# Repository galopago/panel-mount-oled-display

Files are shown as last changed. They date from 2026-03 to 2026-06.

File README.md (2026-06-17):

# Panel-mount OLED display — PCB sources

Open-source KiCad designs for a two-board stack that drives a bare 0.96" I2C OLED (128×64) with screw terminals. The boards are meant to fit a 48×29 mm panel-mount enclosure; this repository contains the PCB sources and Gerbers only.

**Full project guide** (assembly, enclosure, BOM with buy links, practical notes):  
[Panel-mount 0.96" bare OLED with screw terminals](https://galopago.github.io/english/panel-mount-oled-display-en/)

## Two-board design

| Board | Folder | Role |
|---|---|---|
| Display board | [`display-board/`](display-board/) | Bare OLED flex (handsoldering footprint), XC6206 3.3 V LDO, auto-reset network, I2C coupling, six 0805 indicator LEDs with independent anode/cathode terminals, 1×8 header to the connector board |
| Connector board | [`connector-board/`](connector-board/) | Double-level 2×8 screw terminals (3.5 mm pitch); routes signals to the field wiring |

The stack is joined with 1×8 pin headers and a spacer so the terminals stay reachable from the side.

## Schematic

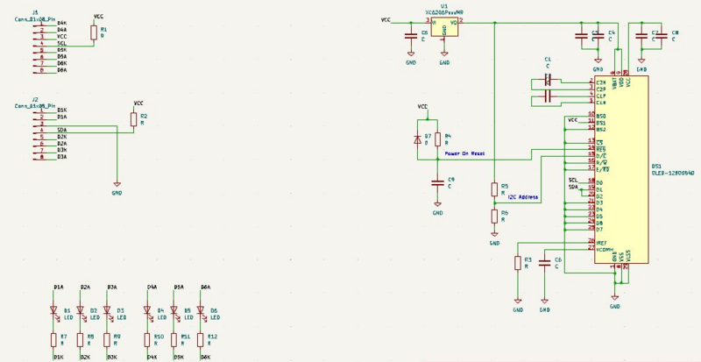
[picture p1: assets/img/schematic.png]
Display and connector board schematic


## Photos

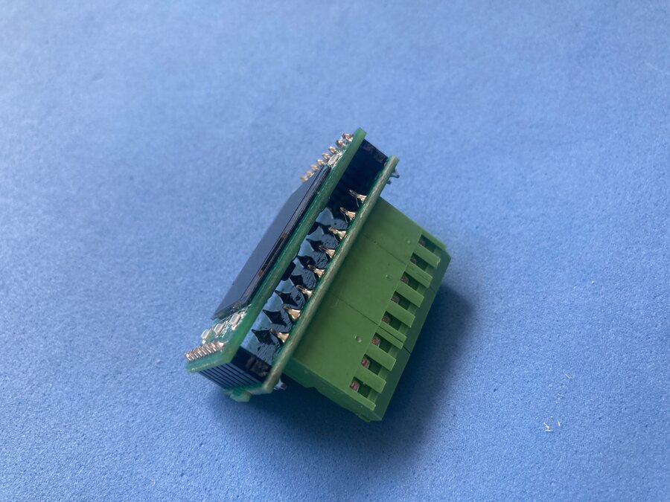
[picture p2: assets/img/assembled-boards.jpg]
Stacked display and connector boards


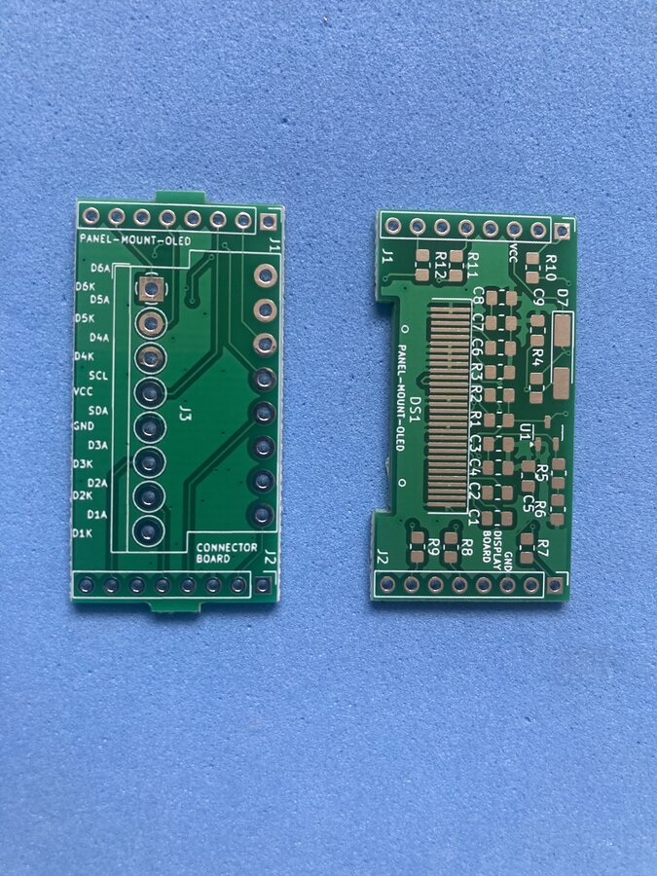
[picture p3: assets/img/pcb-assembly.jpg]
Populated display board


## Repository layout

```
display-board/          KiCad project (.kicad_pro, .kicad_sch, .kicad_pcb)
connector-board/        KiCad project
library/                Custom terminal-block footprints
assets/pdf/             Component and OLED datasheets
assets/img/             Schematic and board photos
```

Gerber archives are under each board folder:

- `*/gerber/single/*.zip` — single-board fabrication
- `*/gerber/panel/*.zip` — panel fabrication

## Ordering PCBs

Upload the Gerber ZIP of your choice to your PCB fab:

| Board | Single | Panel |
|---|---|---|
| Display | [`display-board-single.zip`](display-board/gerber/single/panel-mount-oled-display-display-board-single.zip) | [`display-board-panel.zip`](display-board/gerber/panel/panel-mount-oled-display-display-board-panel.zip) |
| Connector | [`connector-board-single.zip`](connector-board/gerber/single/panel-mount-oled-display-connector-board-single.zip) | [`connector-board-panel.zip`](connector-board/gerber/panel/panel-mount-oled-display-connector-board-panel.zip) |

Panel Gerbers are kept within a **100 mm × 100 mm** outline. That size fits the low-cost tier offered by many PCB fabs, so panel orders tend to stay inexpensive even when you need several boards at once.

## Opening in KiCad

Open each `.kicad_pro` file separately (KiCad 7 or newer). The local footprint library in [`library/`](library/) is referenced by the projects.

## Host interface

No on-board firmware. Any host with I2C (Arduino, ESP32, Raspberry Pi Pico, etc.) can drive the SSD1306-compatible display. Wire VCC, GND, SCL, and SDA to the screw terminals; route the six LED pairs to status signals as needed. I2C address selection is configurable on the display board (see schematic).

## What is not in this repo

Enclosure sourcing, step-by-step assembly, and the full bill of materials with purchase links are covered in the [project article](https://galopago.github.io/english/panel-mount-oled-display-en/) linked above.

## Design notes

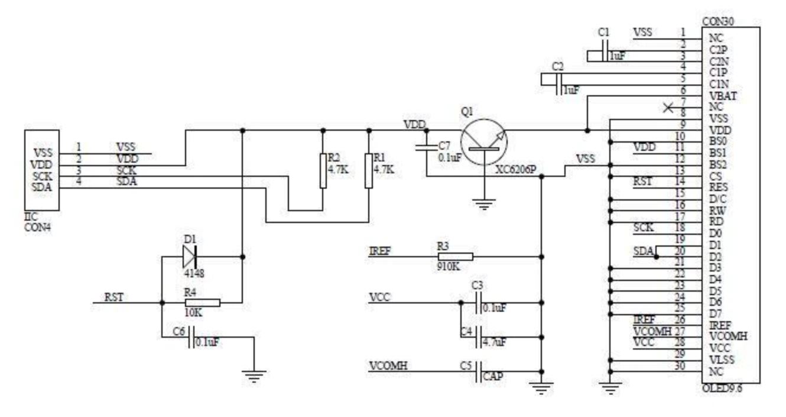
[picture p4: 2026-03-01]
assets/pdf/IIC_SSD1306Panel.JPG

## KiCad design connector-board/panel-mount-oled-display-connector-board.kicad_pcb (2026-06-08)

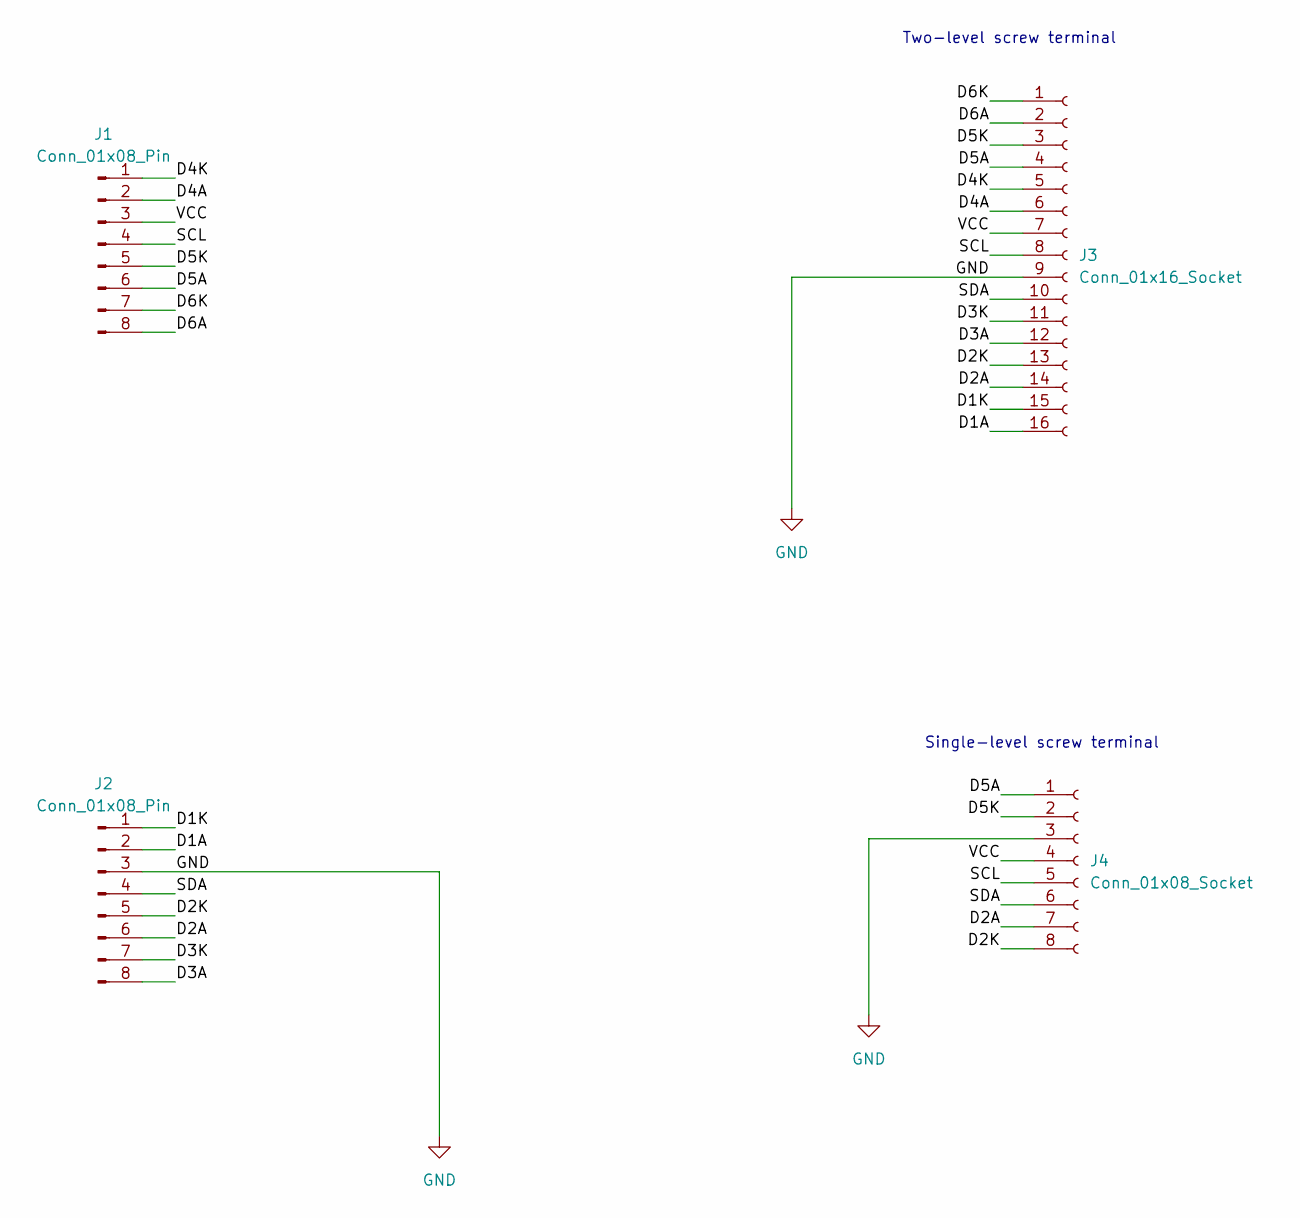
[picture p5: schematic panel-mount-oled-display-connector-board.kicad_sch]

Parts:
J1, J2: Conn_01x08_Pin; PinHeader_1x08_P2.54mm_Vertical
J3: Conn_01x16_Socket; TerminalBlock_DoubleLevel_2x08_P3.50mm_Horizontal
J4: Conn_01x08_Socket; TerminalBlock_4Ucon_1x08_P3.50mm_Horizontal

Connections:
/D1A: J2.2, J3.16
/D1K: J2.1, J3.15
/D2A: J2.6, J3.14, J4.7
/D2K: J2.5, J3.13, J4.8
/D3A: J2.8, J3.12
/D3K: J2.7, J3.11
/D4A: J1.2, J3.6
/D4K: J1.1, J3.5
/D5A: J1.6, J3.4, J4.1
/D5K: J1.5, J3.3, J4.2
/D6A: J1.8, J3.2
/D6K: J1.7, J3.1
/SCL: J1.4, J3.8, J4.5
/SDA: J2.4, J3.10, J4.6
/VCC: J1.3, J3.7, J4.4
GND: J2.3, J3.9, J4.3

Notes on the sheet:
Single-level screw terminal
Two-level screw terminal

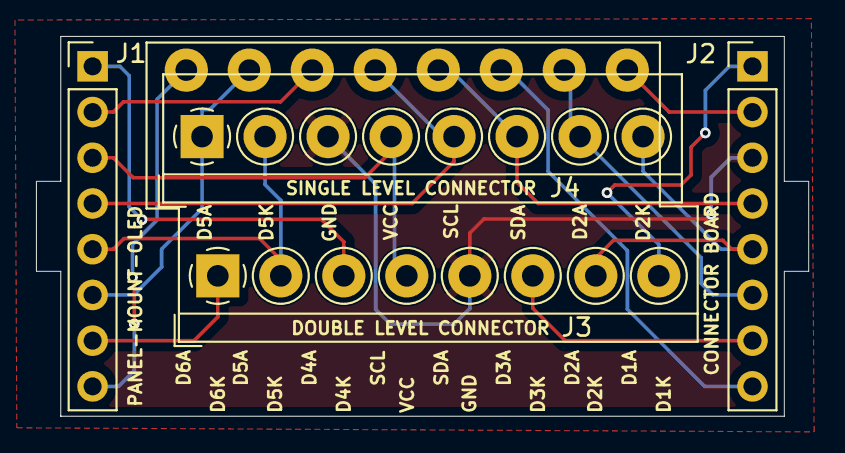
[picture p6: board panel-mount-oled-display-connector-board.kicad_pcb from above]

Board: 2 copper layers, 42.9 x 21.1 mm, 4 parts (0 on the bottom side), 16 nets.

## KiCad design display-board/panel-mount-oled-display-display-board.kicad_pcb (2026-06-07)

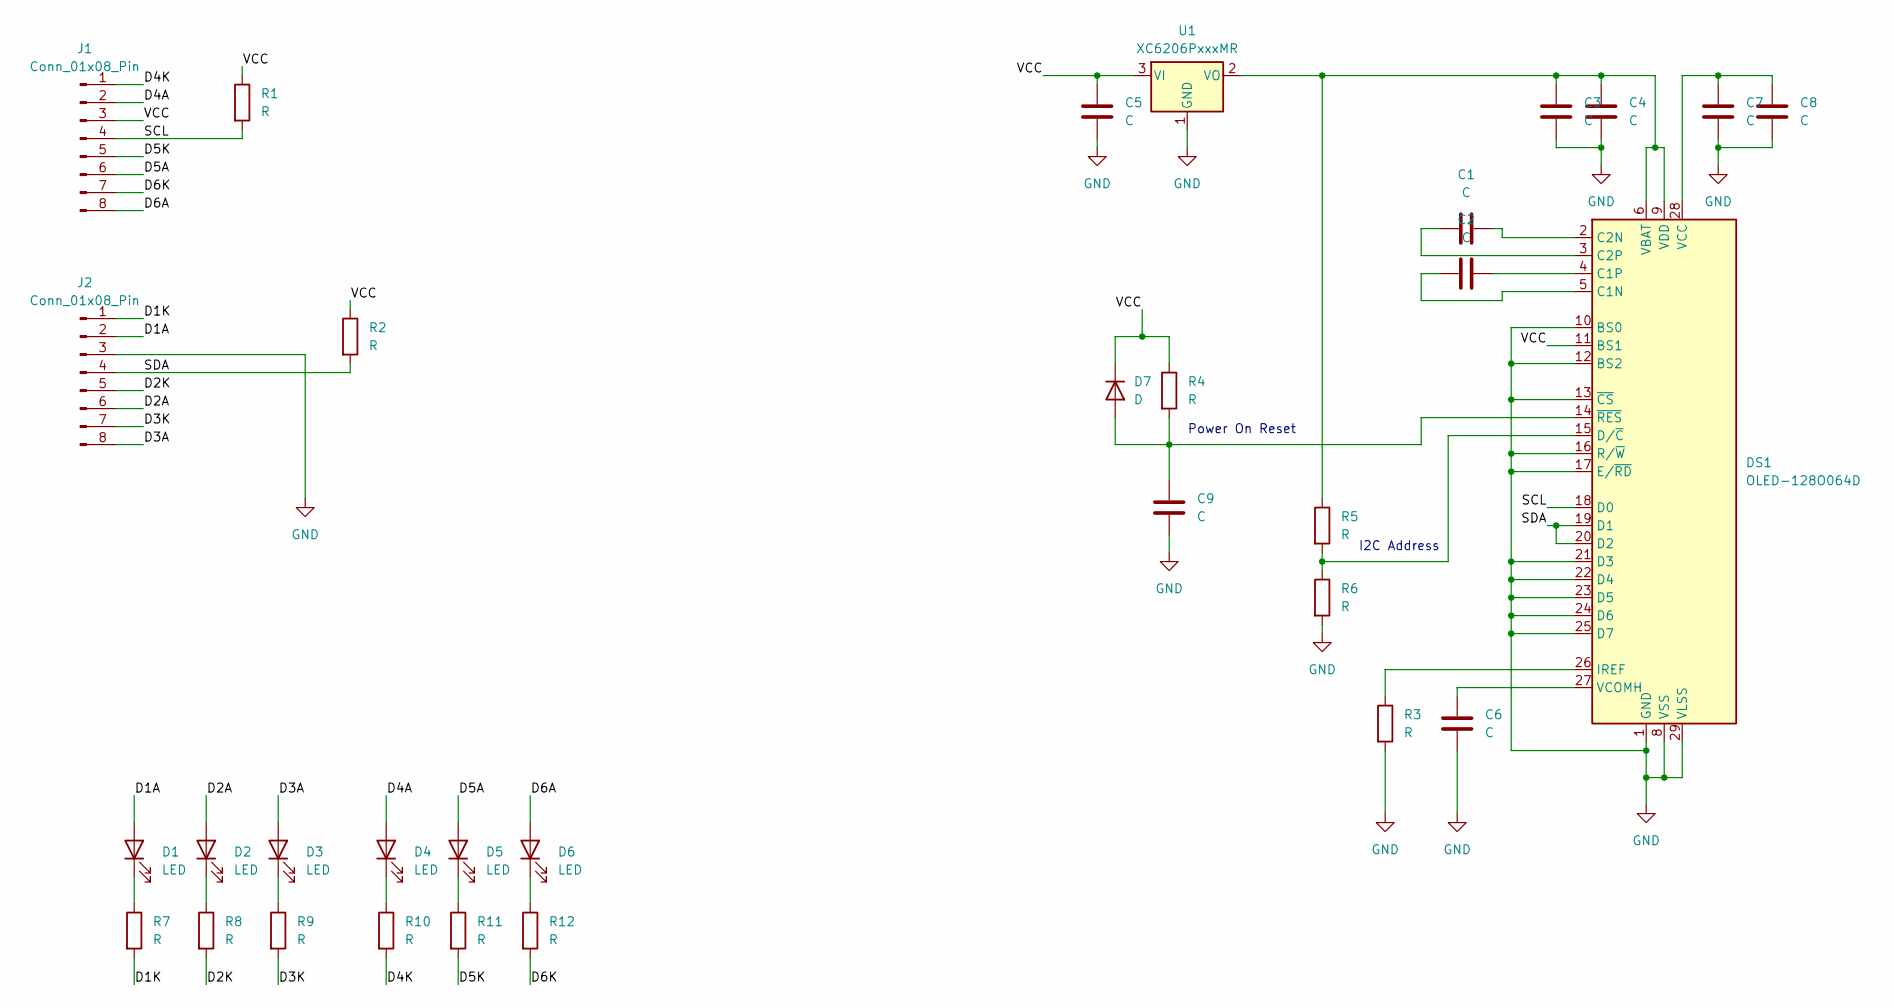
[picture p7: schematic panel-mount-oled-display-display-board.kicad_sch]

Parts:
C1, C2, C3, C4, C5, C6, C7, C8, C9: C; C_0805_2012Metric_Pad1.18x1.45mm_HandSolder
D1, D2, D3, D4, D5, D6: LED; LED_0805_2012Metric_Pad1.15x1.40mm_HandSolder
D7: D; D_MiniMELF_Handsoldering
DS1: OLED-128O064D; OLED-128O064D_Handsoldering
J1, J2: Conn_01x08_Pin; PinHeader_1x08_P2.54mm_Vertical
R1, R2, R3, R4, R5, R6, R7, R8, R9, R10, R11, R12: R; R_0805_2012Metric_Pad1.20x1.40mm_HandSolder
U1: XC6206PxxxMR; SOT-23-3

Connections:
/D1A: D1.2 (A), J2.2
/D1K: J2.1, R7.2
/D2A: D2.2 (A), J2.6
/D2K: J2.5, R8.2
/D3A: D3.2 (A), J2.8
/D3K: J2.7, R9.2
/D4A: D4.2 (A), J1.2
/D4K: J1.1, R10.2
/D5A: D5.2 (A), J1.6
/D5K: J1.5, R11.2
/D6A: D6.2 (A), J1.8
/D6K: J1.7, R12.2
/SCL: DS1.18 (D0), J1.4, R1.2
/SDA: DS1.19 (D1), DS1.20 (D2), J2.4, R2.2
/VCC: C5.2, D7.1 (K), DS1.11 (BS1), J1.3, R1.1, R2.1, R4.1, U1.3 (VI)
GND: C3.1, C4.1, C5.1, C6.1, C7.1, C8.1, C9.1, DS1.1 (GND), DS1.8 (VSS), DS1.10 (BS0), DS1.12 (BS2), DS1.13 (~CS), DS1.16 (R/~W), DS1.17 (E/~RD), DS1.21 (D3), DS1.22 (D4), DS1.23 (D5), DS1.24 (D6), DS1.25 (D7), DS1.29 (VLSS), DS1.30 (GND), J2.3, R3.2, R6.2, U1.1 (GND)
unnamed: D1.1 (K), R7.1
unnamed: D2.1 (K), R8.1
unnamed: D3.1 (K), R9.1
unnamed: D4.1 (K), R10.1
unnamed: D5.1 (K), R11.1
unnamed: D6.1 (K), R12.1
unnamed: C9.2, D7.2 (A), DS1.14 (~RES), R4.2
unnamed: C2.2, DS1.5 (C1N)
unnamed: C2.1, DS1.4 (C1P)
unnamed: C1.1, DS1.2 (C2N)
unnamed: C1.2, DS1.3 (C2P)
unnamed: DS1.15 (D/~C), R5.2, R6.1
unnamed: DS1.26 (IREF), R3.1
unnamed: C3.2, C4.2, DS1.6 (VBAT), DS1.9 (VDD), R5.1, U1.2 (VO)
unnamed: C7.2, C8.2, DS1.28 (VCC)
unnamed: C6.2, DS1.27 (VCOMH)

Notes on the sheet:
I2C Address
Power On Reset

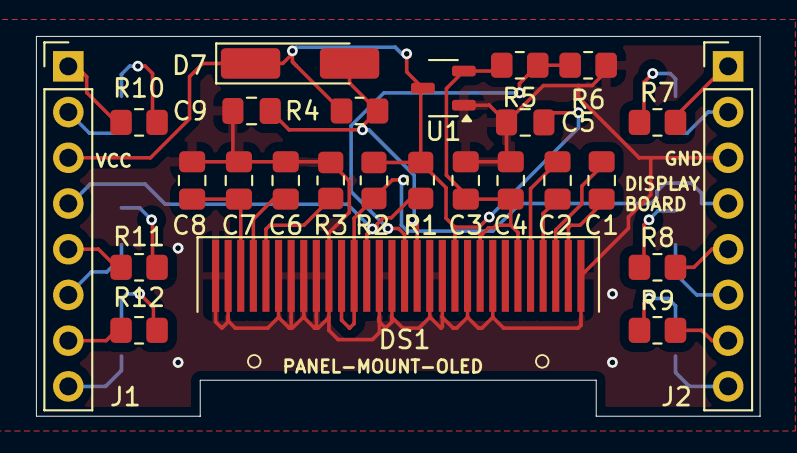
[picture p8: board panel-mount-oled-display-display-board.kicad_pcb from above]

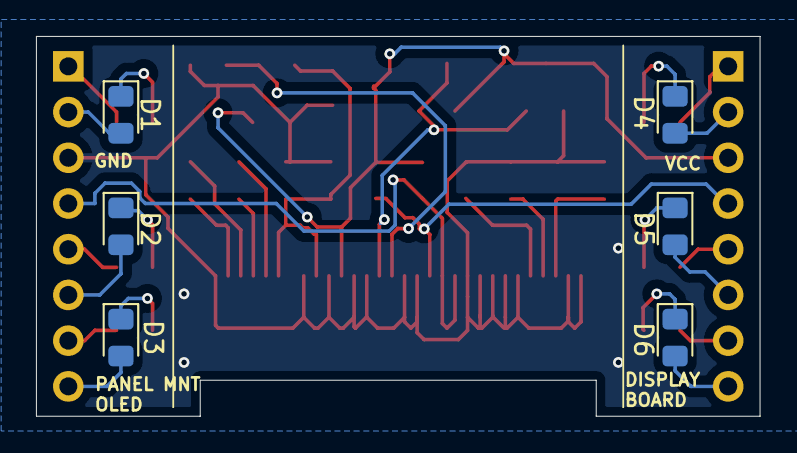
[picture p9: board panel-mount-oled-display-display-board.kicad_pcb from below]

Board: 2 copper layers, 40.2 x 21.1 mm, 32 parts (6 on the bottom side), 32 nets.

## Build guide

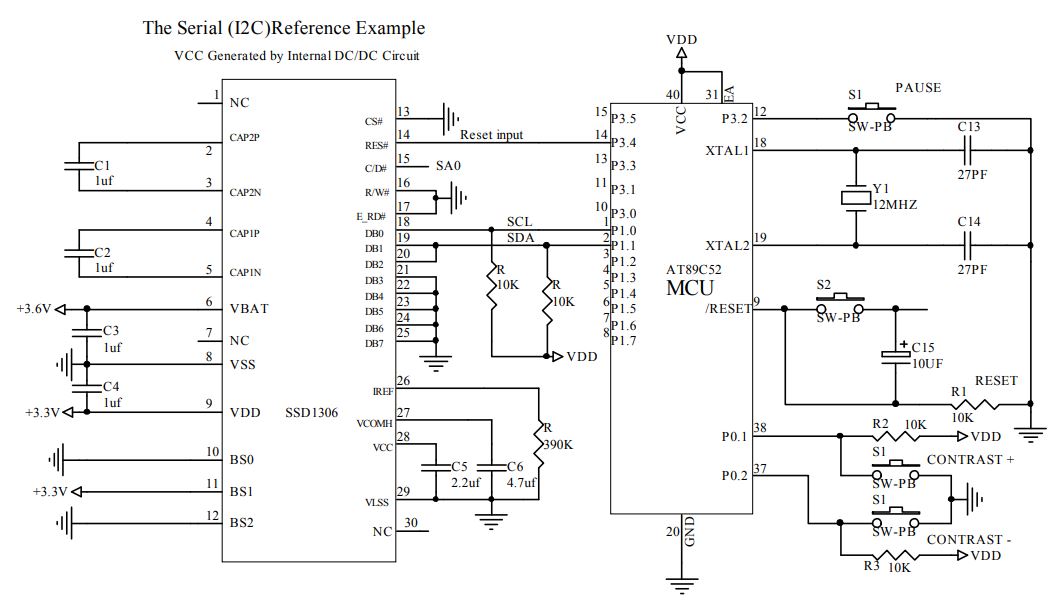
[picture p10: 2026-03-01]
assets/pdf/I2C_HookupGuide.JPG

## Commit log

2026-03-01 Initial commit: KiCad project panel-mount-oled-display
    [panel-mount-oled-display.kicad_pcb, panel-mount-oled-display.kicad_sch]
2026-05-07 Restructure repository into connector-board, display-board, and shared library
    - Replace flat root KiCad project with split connector-board and display-board projects
    - Add shared TerminalBlock_DoubleLevel footprints under library/
    - Include gerber exports (single and panel), fabrication archives, and KiCad backups
    [-B_Cu.gbr, -B_Mask.gbr, -B_Paste.gbr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]
2026-05-09 display: OLED handsolder footprint, schematic/PCB update, datasheets and backups
    - Assign Display_Handsoldering OLED-128O064D_Handsoldering footprint and refresh board
    - Update fp-lib-table and fp-info-cache
    - Add datasheet PDFs, project backup zips, remove superseded connector backup
    [panel-mount-oled-display-display-board.kicad_pcb, panel-mount-oled-display-display-board.kicad_sch]
2026-05-11 Expand display board schematic with additional components
    Update KiCad schematic and PCB to reflect new circuitry. Refresh
    project backup archives and remove superseded backup snapshot.
    [panel-mount-oled-display-display-board.kicad_pcb, panel-mount-oled-display-display-board.kicad_sch]
2026-05-11 display: finish board routing and checkpoint KiCad outputs
    Capture the fully routed display board together with the generated KiCad
    artifacts and fresh backups for this layout milestone.
    [panel-mount-oled-display-display-board.dsn, panel-mount-oled-display-display-board.kicad_pcb, panel-mount-oled-display-display-board.kicad_sch]
2026-05-11 display: add single-board Gerber fabrication files
    Generate Gerber and drill outputs for a single display board, update the
    KiCad plot settings to export into gerber/single, and checkpoint the
    matching fabrication archive and refreshed backup.
    [panel-mount-oled-display-display-board-B_Cu.gbr, panel-mount-oled-display-display-board-B_Mask.gbr, panel-mount-oled-display-display-board-B_Paste.gbr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]
2026-05-11 display: add panel Gerber fabrication files
    Generate the panelized Gerber and drill outputs for the display board,
    archive the fabrication bundle, and checkpoint the latest KiCad backups.
    [-B_Cu.gbr, -B_Mask.gbr, -B_Paste.gbr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]
2026-06-07 display: widen PCB cutout and reposition LEDs clear of bezel
    Expand the display mounting area slightly to fit marginally wider
    OLED modules, and shift the status LEDs so they are not obstructed
    by the panel bezel.
    [panel-mount-oled-display-display-board.kicad_pcb]
2026-06-07 display: regenerate single-board Gerber fabrication files
    Export updated Gerber and drill outputs for a single display board
    from the latest PCB layout.
    [panel-mount-oled-display-display-board-B_Cu.gbr, panel-mount-oled-display-display-board-B_Mask.gbr, panel-mount-oled-display-display-board-B_Paste.gbr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]
2026-06-07 display: update KiCad project backup
    Rotate display board KiCad backup after regenerating single-board
    Gerber fabrication files.
2026-06-07 display: regenerate panel Gerber fabrication files
    Export panelized Gerber and drill outputs for production fabrication
    of the display board from the latest PCB layout.
    [-B_Cu.gbr, -B_Mask.gbr, -B_Paste.gbr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]
2026-06-08 connector: add dual screw-terminal connector options
    Add a new connector on the connector board to support either
    single-level or two-level screw terminal blocks, providing
    flexibility to expose more LEDs when needed.
    [panel-mount-oled-display-connector-board.dsn, panel-mount-oled-display-connector-board.kicad_pcb, panel-mount-oled-display-connector-board.kicad_sch]
2026-06-08 display: update KiCad project backup
    Rotate display board KiCad backup after connector board schematic
    and layout updates.
2026-06-08 connector: regenerate single-board Gerber fabrication files
    Export Gerber and drill outputs for a single connector board from
    the latest PCB layout.
    [panel-mount-oled-display-connector-board-B_Cu.gbr, panel-mount-oled-display-connector-board-B_Mask.gbr, panel-mount-oled-display-connector-board-B_Paste.gbr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]
2026-06-08 connector: update KiCad project backup
    Rotate connector board KiCad backup after regenerating single-board
    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
2026-06-08 connector: regenerate panel Gerber fabrication files
    of the connector board from the latest PCB layout.
    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
    [-B_Cu.gbr, -B_Mask.gbr, -B_Paste.gbr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]
2026-06-17 Add PCB-focused README with optimized board images.
    Document the two-board KiCad design and Gerber locations, and add web-friendly photos plus a resized schematic for GitHub.
2026-06-17 Note 100 mm panel Gerber limit in README.
    Clarify that panel outlines stay within 100 mm × 100 mm to qualify for low-cost PCB fab tiers.
2026-06-17 Update KiCad project backups for display and connector boards.
    Replace the outdated display-board archive and add the latest connector-board backup.
